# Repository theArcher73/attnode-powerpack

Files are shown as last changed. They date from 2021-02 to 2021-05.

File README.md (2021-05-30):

# AttNo.de-powerpack, a adapter-pcb to use 3.3-15V
 AddOn to use the [attnode](https://attno.de) v2/v3 with 3.3-15V DC

This small pcb allows to run the [attnode](https://attno.de) with an operating voltage between 3.3 and 15V, for example with a USB power supply, a LiPo or any other fixed voltage power supply.

It has the shape of the CR2032 battery clip and is soldered directly onto the [attnode](https://attno.de) instead of the CR2032-Clip.

Therefore, when ordering the pcb's, a smaller pcb thickness can be used if possible, I have had good experiences with 1.2mm.

The power supply can be either via the JST socket, or the two pads directly on the pcb. In this case, the JST socket must not be soldered.

The voltage source must provide at least 120 mA.

Update 26.05.2021: add a Voltage divider added to monitor the Vin with an ADC pin of the ATTiny. The resistance ratio must be determined based on Vin, here are some sample values. The voltage at the ADC pad should not exceed 2.1V.

  Vin | Vmax |  R1 | R2
------|------|-----|----
3.7V | 4.2V | 1M | 1M
USB | 5.25V | 1M5 | 1M
9V | 11V | 6M8 | 1M5
12V | 15.4V | 10M | 1M5

Attention! Pay attention to the peak voltage, which is higher than the nominal voltage for many batteries!

More information can be found [here](https://www.attno.de/blog/2021-01-08).

 front  | back       
--------|--------
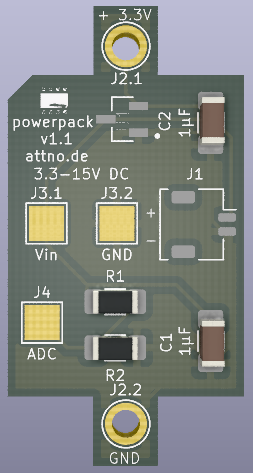
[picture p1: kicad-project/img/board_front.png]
front view
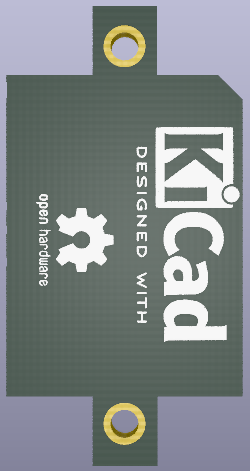
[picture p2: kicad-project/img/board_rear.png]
Rear view
 | 

## Disclaimer

The documentation of the attno.de-powerpack is distributed in the hope that it will be useful, but WITHOUT ANY WARRANTY; without even the implied warranty of MERCHANTABILITY or FITNESS FOR A PARTICULAR PURPOSE.

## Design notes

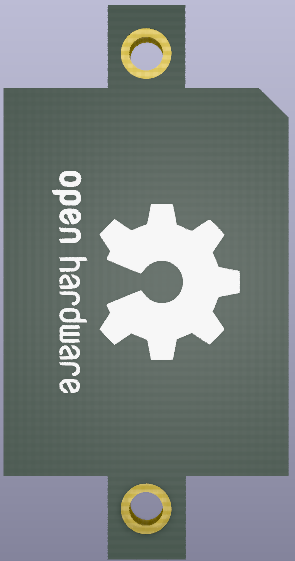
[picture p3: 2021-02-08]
kicads-project/img/board_rear.png

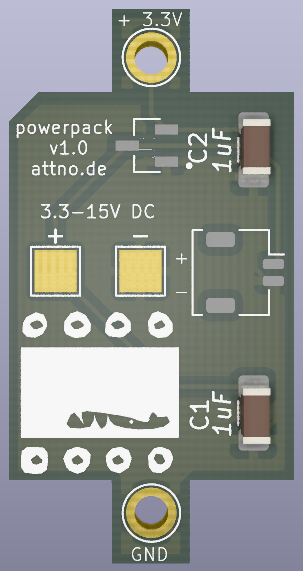
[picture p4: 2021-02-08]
kicads-project/img/board_front.png

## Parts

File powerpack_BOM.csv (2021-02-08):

Reference | Quantity | Value | Bauteil | Footprint
C1, C2 | 2 | 1µF | Capacitor SMD 1206 | Capacitor_SMD:C_1206_3216Metric_Pad1.33x1.80mm_HandSolder
J1 | 1 | Power_in 3.3-15V | JST 2pin 1mm horizontal | Connector_JST:JST_SHL_SM02B-SHLS-TF_1x02-1MP_P1.00mm_Horizontal
U1 | 1 | MCP1703T-3302E_CB | MCP 1703-3302E/CB | MCP1703T-3302E_CB:SOT95P255X145-3N

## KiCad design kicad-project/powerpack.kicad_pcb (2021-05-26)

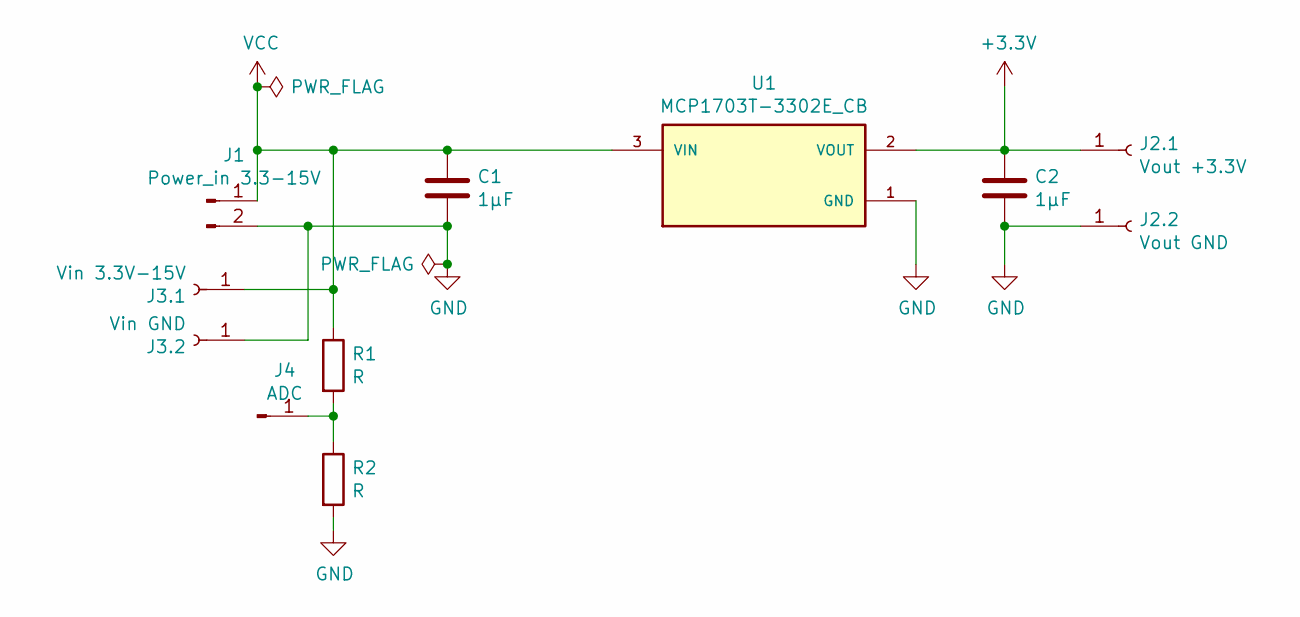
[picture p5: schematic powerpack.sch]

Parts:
C1, C2: 1µF; C_1206_3216Metric_Pad1.33x1.80mm_HandSolder
J1: Power_in 3.3-15V; JST_SHL_SM02B-SHLS-TF_1x02-1MP_P1.00mm_Horizontal
J2.1: Vout +3.3V; TestPoint_Plated_Hole_D2.0mm
J2.2: Vout GND; TestPoint_Plated_Hole_D2.0mm
J3.1: Vin 3.3V-15V; TestPoint_Pad_2.5x2.5mm
J3.2: Vin GND; TestPoint_Pad_2.5x2.5mm
J4: ADC; TestPoint_Pad_2.5x2.5mm
R1, R2: R; R_1206_3216Metric_Pad1.30x1.75mm_HandSolder
U1: MCP1703T-3302E_CB; SOT95P255X145-3N; MPN MCP1703T-3302E/CB

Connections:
+3V3: C2.1, J2.1.1, U1.2 (VOUT)
GND: C1.2, C2.2, J1.2, J2.2.1, J3.2.1, R2.2, U1.1 (GND)
unnamed: J4.1, R1.2, R2.1
VCC: C1.1, J1.1, J3.1.1, R1.1, U1.3 (VIN)

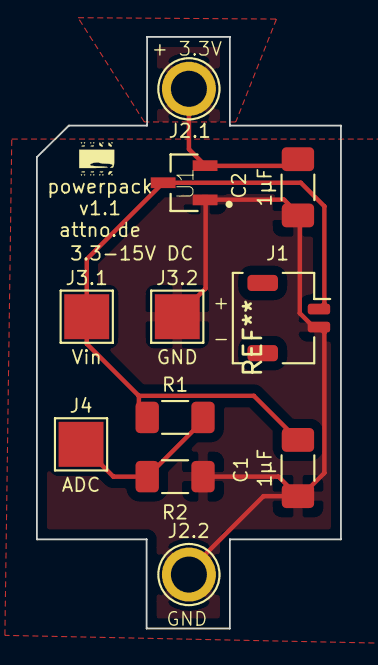
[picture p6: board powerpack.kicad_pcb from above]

Board: 2 copper layers, 16.9 x 32.9 mm, 11 parts (0 on the bottom side), 4 nets.

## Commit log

2021-02-08 added readme and bugfix
    [CO2-PlatineMZ-H19-B_Cu.gbr, CO2-PlatineMZ-H19-B_Mask.gbr, CO2-PlatineMZ-H19-B_Paste.gbr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]
2021-02-08 add BOM
    [powerpack-B_Cu.gbr, powerpack-B_Mask.gbr, powerpack-B_Paste.gbr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]
2021-02-08 add link to powerpack
2021-05-26 update Silk and folder
    [powerpack-B_Cu.gbr, powerpack-B_Mask.gbr, powerpack-B_Paste.gbr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]
